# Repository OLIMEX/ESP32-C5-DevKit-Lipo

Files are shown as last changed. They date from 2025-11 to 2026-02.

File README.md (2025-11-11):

# ESP32-C5-DevKit-Lipo
Dual band 2.4Ghz and 5Ghz WiFi 6, Bluetooth 5 LE, Zigbee, Thread, Matter development board UEXT, USB programming, USB JTAG and LiPo battery UPS

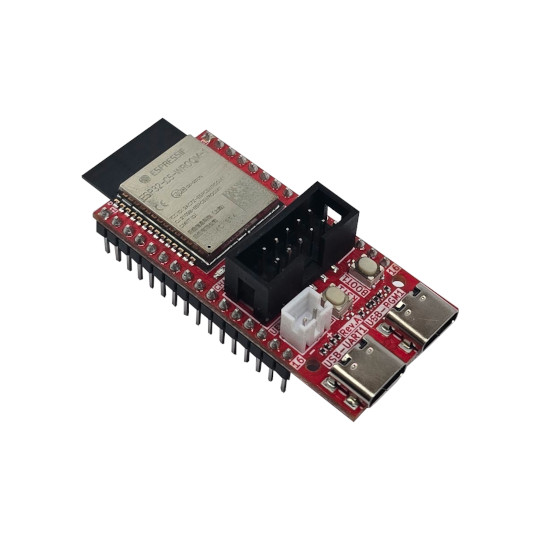
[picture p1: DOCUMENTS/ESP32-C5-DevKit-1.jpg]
ESP32-C5-DevKit-1


https://www.olimex.com/Products/IoT/ESP32-C5/ESP32-C5-DevKit-Lipo/open-source-hardware

Features:

* 32 bit RISC-V processor 240Mhz
* Dual-Band Wi-Fi (2.4 GHz + 5 GHz)
* Bluetooth 5, Zigbee, Thread, Matter
* 8 MB Flash + 4 MB RAM
* UEXT connector
* USB-C (Power & Debug)
* USB-C JTAG
* Boot & Reset buttons
* Extension connector
* 0.9" (22.86 mm) space between the headers
* LiPo UPS charger & step-up converter
* Status LEDs
* Two mouting holes
* Dimensions 53x25mm

## Licenses

* Hardware is released under CERN Open Hardware Licence Version 2 - Strongly Reciprocal, all silkscreen credits to Olimex should remain;
* Software is released under MIT Licensee
* Documentation is released under CC BY-SA 4.0

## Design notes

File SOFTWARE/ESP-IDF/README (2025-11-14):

# ESP32-C5-DevKit-Lipo_low_power_demo - esp-idf project
# After power-on the user led starts blinking. When you hold down USER BUTTON, the LED stops blinking, and the board enters deep_sleep.
# To wake-up the board, you have to press RST button of the board.

#
# How to build the project:
#

# 1. Download esp-idf master branch or tag v5.5.1 (this project has been built with v5.5.1 tag)

git clone https://github.com/espressif/esp-idf.git

# OR

git clone https://github.com/espressif/esp-idf.git -b "v5.5.1"

# 2. Install esp-idf (do this one time only)
# 2.1 Go to esp-idf dir:

cd esp-idf

# 2.2 Run installation script. This will download and install all dependencies

./install.sh

# 3. Export esp-idf to PATH (you must do this every time, when you open terminal)
# 3.1 go to the esp-idf path:

cd PATH_TO_ESP-IDF/esp-idf

# 3.2 Execute the following command as it is, including the . symbol
. ./export.sh

# 3.3 go to the project directory
cd PATH/ESP32-C5-DevKit-Lipo_low_power_demo

# 4. Set target to esp32-c5 (one time only)

idf.py set-target esp32c5

# OPTIONAL: Change  sdkconfig  settings

idf.py menuconfig

# Build:

idf.py build

# Flash (change PORT with the actual port, related to ESP32-C5-EVB)
idf.py flash -p PORT

If everything is done after uploading the project, the led will flash 3 times, then blink evry second.

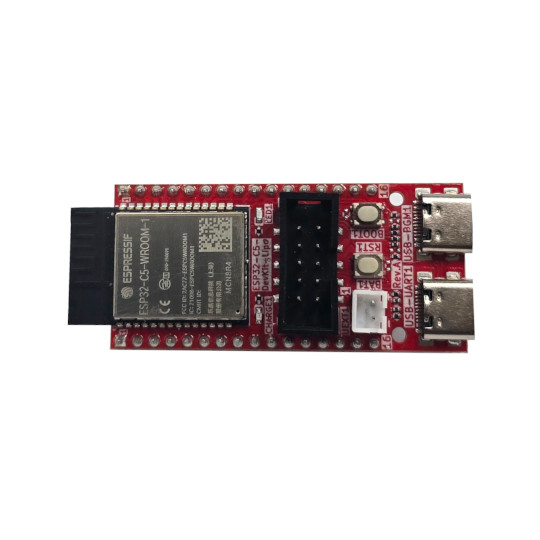
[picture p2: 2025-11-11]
DOCUMENTS/ESP32-C5-DevKit-2.jpg

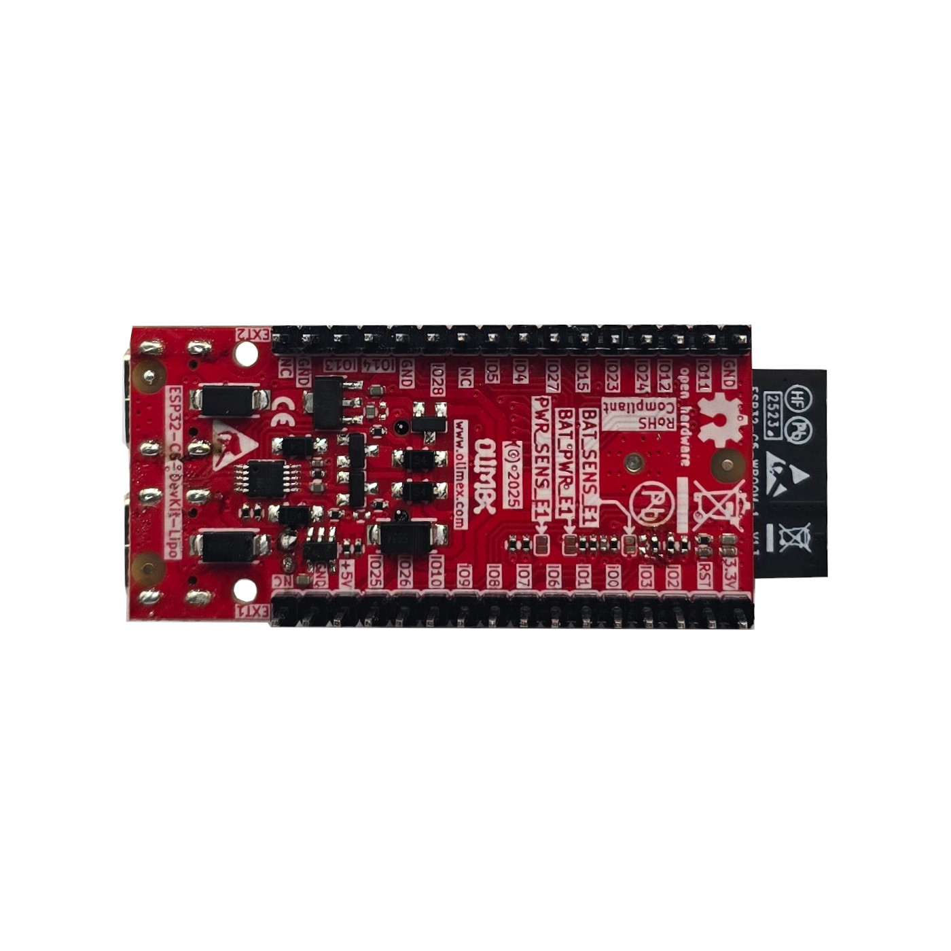
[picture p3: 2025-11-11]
DOCUMENTS/ESP32-C5-DevKit-3.jpg

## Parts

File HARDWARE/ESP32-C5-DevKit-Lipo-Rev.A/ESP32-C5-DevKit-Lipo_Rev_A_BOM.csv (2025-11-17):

Id | Designator | Footprint | Quantity | Designation | Supplier and ref
1 | BOOT1,RST1 | YTS-A016-X | 2 | YTS-A016-X
2 | LED1 | LED_0603_KA | 1 | LED/Green/0603
3 | MH1,MH2 | Mounting_Hole_Drill-2.1mm_Clerance-4mm | 2 | Drill-2.1mm_Clerance-4mm
4 | CHARGE1 | LED_0603_KA | 1 | LED/Yellow/0603
5 | BAT1 | LIPO_BAT_VERTICAL_DW02S | 1 | DW02S
6 | R6,R7 | R_0402_5MIL_DWS | 2 | 33R/R0402
7 | C13,C14 | C_0402_5MIL_DWS | 2 | NA(100nF/10V/20%/X5R/C0402)
8 | FID3,FID4 | Fiducial1x3_Paste | 2 | Fiducial
9 | R2,R5,R1,R3 | R_0402_5MIL_DWS | 4 | 5.1k/1%/R0402
10 | U3 | ESP32-C5-WROOM-1-N4-UNIVERSAL_MODULE | 1 | ESP32-C5-WROOM-1-N8R4
11 | UEXT1 | GBH-254-SMT-10 | 1 | P-B-V-10-LF
12 | R27,R8,R11,R22 | R_0402_5MIL_DWS | 4 | 2.2k/R0402
13 | TVS4,TVS2,TVS1,TVS3 | D_0402_5MIL_DWS | 4 | GG0402052R542P
14 | USB-UART1,USB-PGM1 | USB2.0_TYPE-C(A40-00119-A52-12)_Paste | 2 | USB-C-16P-F(A40-00119-A52-12)
15 | C6,C5 | C_0402_5MIL_DWS | 2 | NA(150pF/50V/2%/NP0/C0402)
16 | FID1,FID2,FID5,FID6 | Fiducial1x3 | 4 | Fiducial
17 | R18,R17,R24 | R_0402_5MIL_DWS | 3 | 470k/R0402
18 | R10,R9,R4,R13,R12 | R_0402_5MIL_DWS | 5 | 10k/R0402
19 | D3,D2,D1 | SMA-KA | 3 | 1N5822/SS34/SMA
20 | C11,C8,C3 | C_0402_5MIL_DWS | 3 | 100nF/10V/20%/X5R/C0402
21 | D7,D5,D6,D4 | SOD-123_1C-2A_KA | 4 | 1N5819S4(SOD-123)
22 | U2 | MSOP-10_Pitch-0.5mm_3.00x3.00x1.00mm | 1 | CH340X(MSOP-10)
23 | R19,R20 | R_0402_5MIL_DWS | 2 | 1k/R0402
24 | R16 | R_0402_5MIL_DWS | 1 | 4.7k/R0402
25 | PWR_SENS_E1,BAT_SENS_E1,BAT_PWR_E1 | SJ_1_SMALLER | 3 | Opened
26 | T2,T1 | SOT23 | 2 | BC817-40(SOT23)
27 | R21,R14 | R_0402_5MIL_DWS | 2 | 0R/R0402
28 | U1 | SOT-23-5 | 1 | TP4054-42-SOT25-R
29 | C7,C12,C10,C2,C1 | C_0402_5MIL_DWS | 5 | 10uF/6.3V/20%/X5R/C0402
30 | C9 | C_0402_5MIL_DWS | 1 | NA(10uF/6.3V/20%/X5R/C0402)
31 | R25 | R_0402_5MIL_DWS | 1 | 220R/R0402
32 | C4 | C_0402_5MIL_DWS | 1 | 1uF/6.3V/10%/X5R/C0402
33 | EXT1,EXT2 | HN1x16 | 2 | HN1x16
34 | VR1 | SOT89-3 | 1 | WL9005P3-33(SOT89-3)
35 | R23 | R_0402_5MIL_DWS | 1 | 220k/R0402
36 | R15 | R_0402_5MIL_DWS | 1 | NA(0R/R0402)
37 | R26 | R_0402_5MIL_DWS | 1 | NA(10k/R0402)
38 | FET1 | SOT23 | 1 | IRLML6402TRPbF

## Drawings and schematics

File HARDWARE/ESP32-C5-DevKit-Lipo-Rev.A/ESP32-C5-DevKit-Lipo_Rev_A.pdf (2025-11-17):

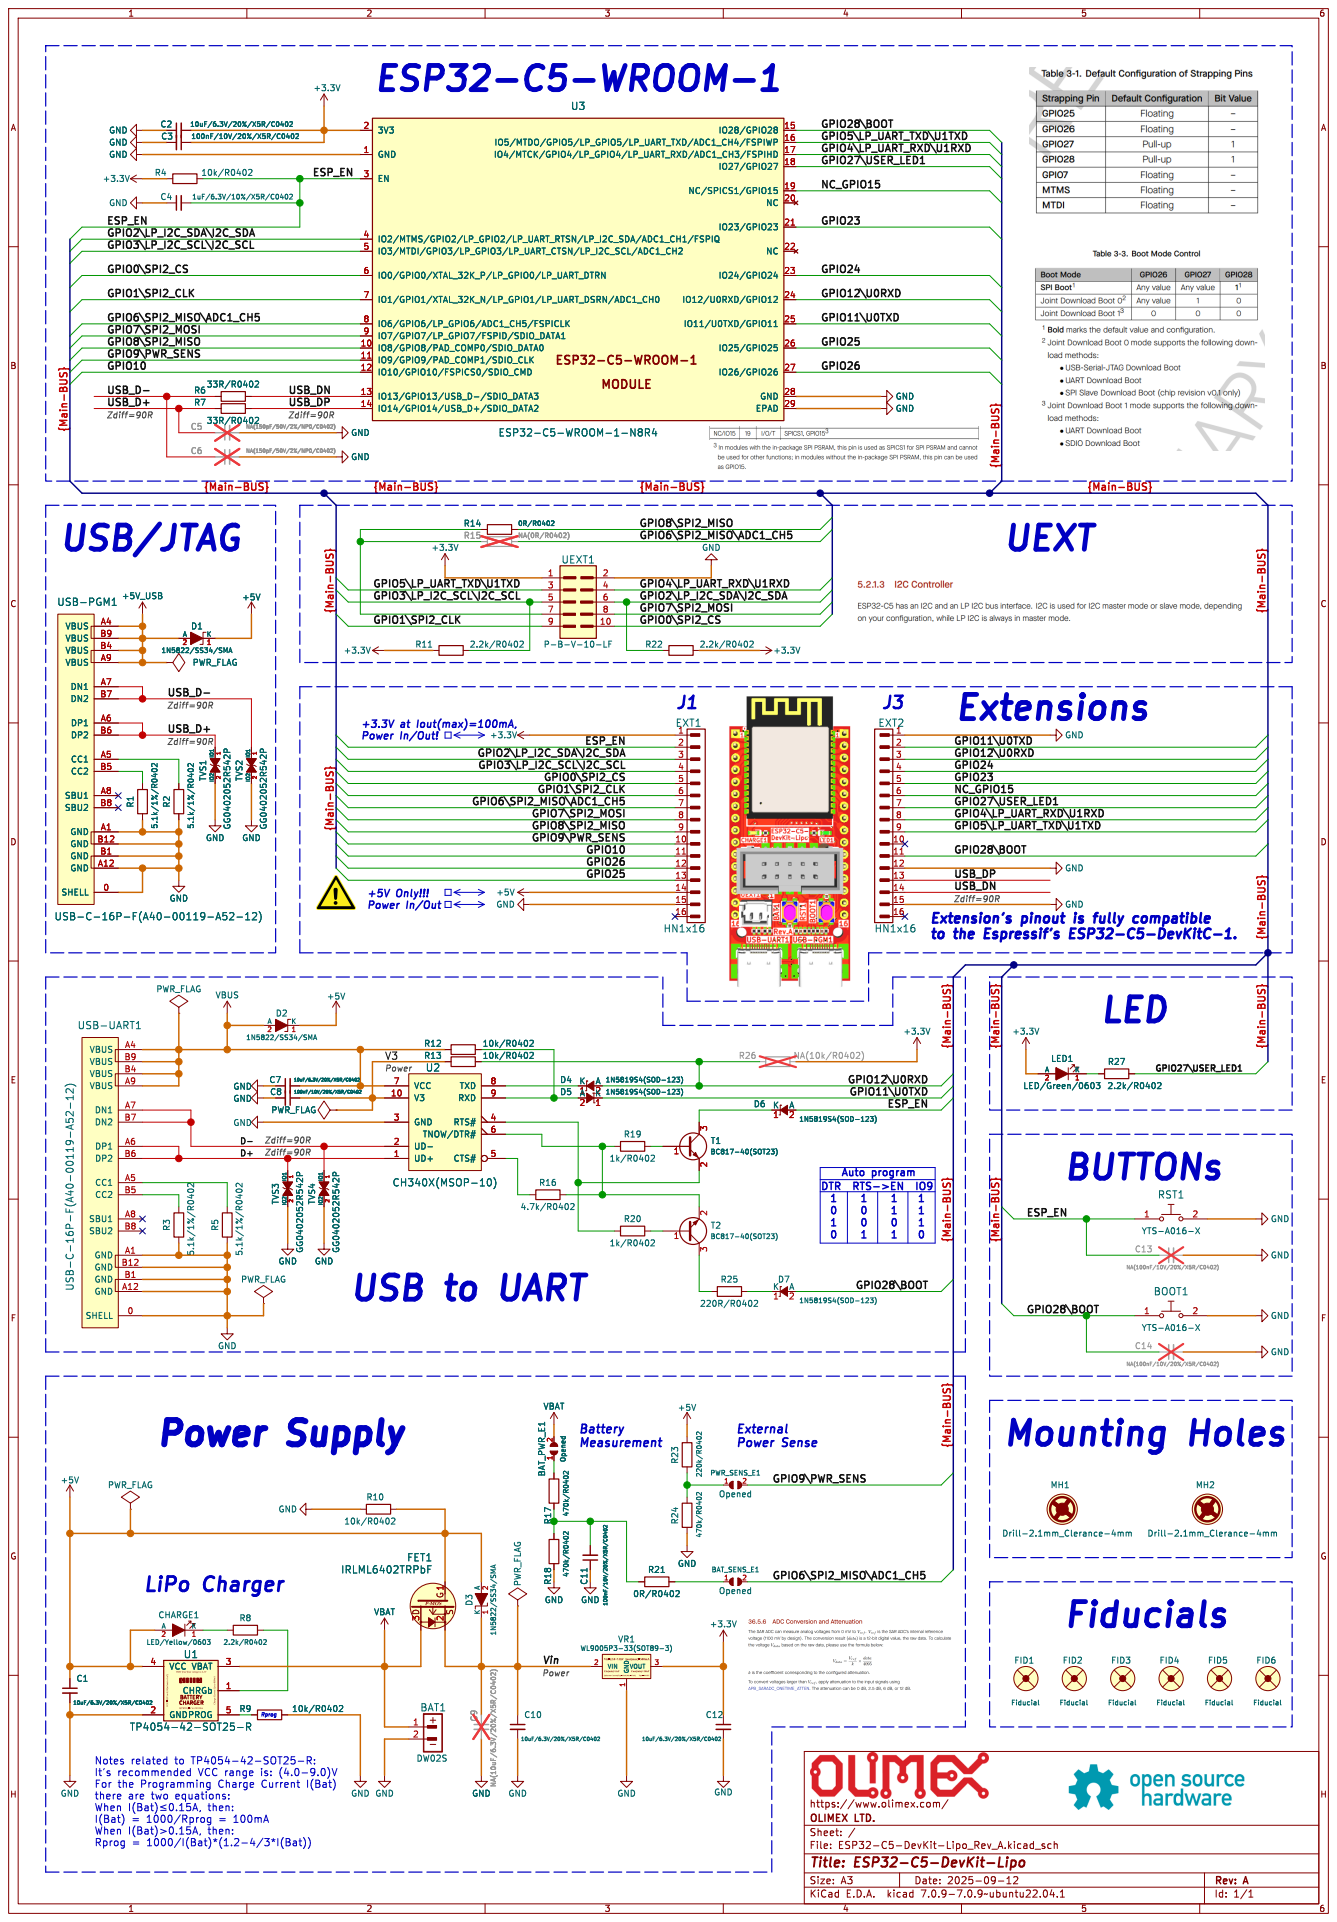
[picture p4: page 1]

2 D3 1N5822/SS34/SMA GND GND C9 NA(10uF/6.3V/20%/X5R/C0402) +5V

+3.3V at Iout(max)=100mA, Power In/Out! +5V Only!!! Power In/Out

to the Espressif's ESP32-C5-DevKitC-1. 0

QuiescentCurrent(Typ=0.3uA;Max=0.7uA) Topr=-40~85C Vin=(2.0~7.0)V GND

Notes related to TP4054-42-SOT25-R:
there are two equations: When þÿI(Bat)"d0.15A, then:

Id: 1/1 Title: ESP32-C5-DevKit-Lipo

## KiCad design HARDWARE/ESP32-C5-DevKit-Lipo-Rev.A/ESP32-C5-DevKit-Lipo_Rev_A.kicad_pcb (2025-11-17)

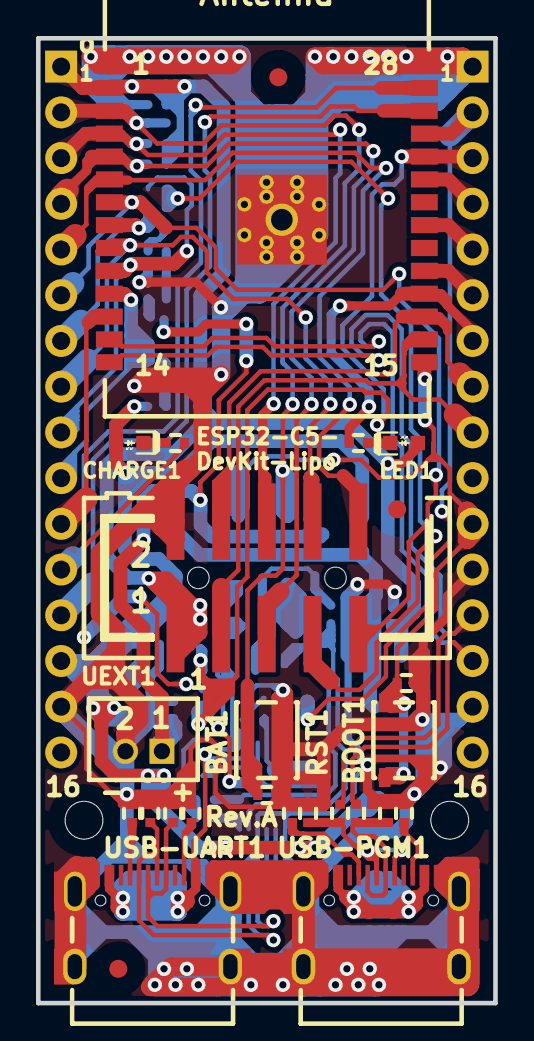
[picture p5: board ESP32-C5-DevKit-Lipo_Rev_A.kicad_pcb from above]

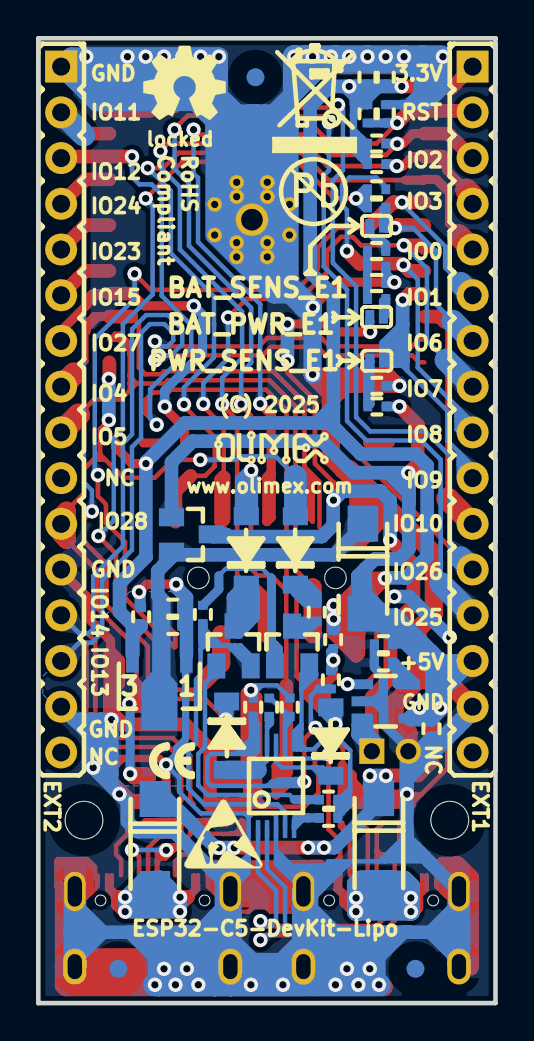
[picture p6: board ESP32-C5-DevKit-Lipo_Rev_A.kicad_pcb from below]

Board: 2 copper layers, 25.4 x 53.6 mm, 86 parts (56 on the bottom side), 58 nets.

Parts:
BAT1: DW02S; LIPO_BAT_VERTICAL_DW02S
BAT_PWR_E1: Opened; SJ_1_SMALLER
BAT_SENS_E1: Opened; SJ_1_SMALLER
BOOT1: YTS-A016-X
C1, C2, C7, C10, C12: 10uF/6.3V/20%/X5R/C0402; C_0402_5MIL_DWS
C3, C8, C11: 100nF/10V/20%/X5R/C0402; C_0402_5MIL_DWS
C4: 1uF/6.3V/10%/X5R/C0402; C_0402_5MIL_DWS
C5, C6: NA(150pF/50V/2%/NP0/C0402); C_0402_5MIL_DWS
C9: NA(10uF/6.3V/20%/X5R/C0402); C_0402_5MIL_DWS
C13, C14: NA(100nF/10V/20%/X5R/C0402); C_0402_5MIL_DWS
CHARGE1: LED/Yellow/0603; LED_0603_KA
D1, D2, D3: 1N5822/SS34/SMA; SMA-KA
D4, D5, D6, D7: 1N5819S4(SOD-123); SOD-123_1C-2A_KA
EXT1, EXT2: HN1x16
FET1: IRLML6402TRPbF; SOT23
FID1, FID2, FID5, FID6: Fiducial; Fiducial1x3
FID3, FID4: Fiducial; Fiducial1x3_Paste
LED1: LED/Green/0603; LED_0603_KA
Logo_OLIMEX_80: Logo_OLIMEX_80
MH1, MH2: Drill-2.1mm_Clerance-4mm; Mounting_Hole_Drill-2.1mm_Clerance-4mm
PWR_SENS_E1: Opened; SJ_1_SMALLER
R1, R2, R3, R5: 5.1k/1%/R0402; R_0402_5MIL_DWS
R4, R9, R10, R12, R13: 10k/R0402; R_0402_5MIL_DWS
R6, R7: 33R/R0402; R_0402_5MIL_DWS
R8, R11, R22, R27: 2.2k/R0402; R_0402_5MIL_DWS
R14, R21: 0R/R0402; R_0402_5MIL_DWS
R15: NA(0R/R0402); R_0402_5MIL_DWS
R16: 4.7k/R0402; R_0402_5MIL_DWS
R17, R18, R24: 470k/R0402; R_0402_5MIL_DWS
R19, R20: 1k/R0402; R_0402_5MIL_DWS
R23: 220k/R0402; R_0402_5MIL_DWS
R25: 220R/R0402; R_0402_5MIL_DWS
R26: NA(10k/R0402); R_0402_5MIL_DWS
RST1: YTS-A016-X
Sign_Antistatic_150: Sign_Antistatic_150
Sign_CE_Small: CE_Sign_Small
Sign_OSHW_7.3x6.0mm: Sign_OSHW_7.3x6.0mm; Sign_OSHW_7.3x6.0mmn
Sign_PB-Free: Sign_PB-Free
Sign_RecycleBin_1: Sign_RecycleBin_1
T1, T2: BC817-40(SOT23); SOT23
TVS1, TVS2, TVS3, TVS4: GG0402052R542P; D_0402_5MIL_DWS
U1: TP4054-42-SOT25-R; SOT-23-5
U2: CH340X(MSOP-10); MSOP-10_Pitch-0.5mm_3.00x3.00x1.00mm
U3: ESP32-C5-WROOM-1-N8R4; ESP32-C5-WROOM-1-N4-UNIVERSAL_MODULE
UEXT1: P-B-V-10-LF; GBH-254-SMT-10
USB-PGM1: USB-C-16P-F(A40-00119-A52-12); USB2.0_TYPE-C(A40-00119-A52-12)_Paste
USB-UART1: USB-C-16P-F(A40-00119-A52-12); USB2.0_TYPE-C(A40-00119-A52-12)_Paste
VR1: WL9005P3-33(SOT89-3); SOT89-3

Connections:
+3.3V: C2.2, C3.1, C12.1, EXT1.1, LED1.2 (A), R4.2, R11.1, R22.2, R26.2, U3.2 (3V3), UEXT1.1, VR1.3 (VOUT)
+5V: C1.1, CHARGE1.2 (A), D1.1 (K), D2.1 (K), D3.2 (A), EXT1.14, FET1.1, R10.1, R23.1, U1.4 (VCC)
+5V_USB: D1.2 (A), USB-PGM1.A4 (VBUS), USB-PGM1.A9 (VBUS), USB-PGM1.B4 (VBUS), USB-PGM1.B9 (VBUS)
/D+: TVS3.1 (IO1), U2.1 (UD+), USB-UART1.A6 (DP1), USB-UART1.B6 (DP2)
/D-: TVS4.1 (IO1), U2.2 (UD-), USB-UART1.A7 (DN1), USB-UART1.B7 (DN2)
/ESP_EN: C4.2, C13.1, D6.2 (A), EXT1.2, R4.1, RST1.1, U3.3 (EN)
/GPIO0\SPI2_CS: EXT1.5, U3.6 (IO0/GPIO0/XTAL_32K_P/LP_GPIO0/LP_UART_D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), UEXT1.10
/GPIO1\SPI2_CLK: EXT1.6, U3.7 (IO1/GPIO1/XTAL_32K_N/LP_GPIO1/LP_UART_D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), UEXT1.9
/GPIO2\LP_I2C_SDA\I2C_SDA: EXT1.3, R22.1, U3.4 (IO2/MTMS/GPIO2/LP_GPIO2/LP_UART_RTSN/LP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), UEXT1.6
/GPIO3\LP_I2C_SCL\I2C_SCL: EXT1.4, R11.2, U3.5 (IO3/MTDI/GPIO3/LP_GPIO3/LP_UART_CTSN/LP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), UEXT1.5
/GPIO4\LP_UART_RXD\U1RXD: EXT2.8, U3.17 (IO4/MTCK/GPIO4/LP_GPIO4/LP_UART_RXD/ADC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), UEXT1.4
/GPIO5\LP_UART_TXD\U1TXD: EXT2.9, U3.16 (IO5/MTDO/GPIO5/LP_GPIO5/LP_UART_TXD/ADC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), UEXT1.3
/GPIO6\SPI2_MISO\ADC1_CH5: BAT_SENS_E1.2, EXT1.7, R15.2, U3.8 (IO6/GPIO6/LP_GPIO6/ADC1_CH5/FSPICLK)
/GPIO7\SPI2_MOSI: EXT1.8, U3.9 (IO7/GPIO7/LP_GPIO7/FSPID/SDIO_DATA1), UEXT1.8
/GPIO8\SPI2_MISO: EXT1.9, R14.2, U3.10 (IO8/GPIO8/PAD_COMP0/SDIO_DATA0)
/GPIO9\PWR_SENS: EXT1.10, PWR_SENS_E1.2, U3.11 (IO9/GPIO9/PAD_COMP1/SDIO_CLK)
/GPIO10: EXT1.11, U3.12 (IO10/GPIO10/FSPICS0/SDIO_CMD)
/GPIO11\U0TXD: D5.1 (K), EXT2.2, U3.25 (IO11/U0TXD/GPIO11)
/GPIO12\U0RXD: D4.2 (A), EXT2.3, R13.2, R26.1, U3.24 (IO12/U0RXD/GPIO12)
/GPIO23: EXT2.5, U3.21 (IO23/GPIO23)
/GPIO24: EXT2.4, U3.23 (IO24/GPIO24)
/GPIO25: EXT1.13, U3.26 (IO25/GPIO25)
/GPIO26: EXT1.12, U3.27 (IO26/GPIO26)
/GPIO27\USER_LED1: EXT2.7, R27.2, U3.18 (IO27/GPIO27)
/GPIO28\BOOT: BOOT1.1, C14.1, D7.2 (A), EXT2.11, U3.15 (IO28/GPIO28)
/NC_GPIO15: EXT2.6, U3.19 (NC/SPICS1/GPIO15)
/USB_D+: C5.1, R7.2, TVS1.1 (IO1), USB-PGM1.A6 (DP1), USB-PGM1.B6 (DP2)
/USB_D-: C6.1, R6.1, TVS2.1 (IO1), USB-PGM1.A7 (DN1), USB-PGM1.B7 (DN2)
/USB_DN: EXT2.14, R6.2, U3.13 (IO13/GPIO13/USB_D-/SDIO_DATA3)
/USB_DP: EXT2.13, R7.1, U3.14 (IO14/GPIO14/USB_D+/SDIO_DATA2)
/V3: C8.1, R13.1, U2.10 (V3)
/Vin: C9.1, C10.1, D3.1 (K), FET1.2, VR1.2 (VIN)
GND: BAT1.2, BOOT1.2, C1.2, C2.1, C3.2, C4.1, C5.2, C6.2, C7.1, C8.2, C9.2, C10.2, C11.1, C12.2, C13.2, C14.2, EXT1.15, EXT2.1, EXT2.12, EXT2.15, R1.1, R2.1, R3.1, R5.1, R9.1, R10.2, R18.2, R24.2, RST1.2, TVS1.2 (IO2), TVS2.2 (IO2), TVS3.2 (IO2), TVS4.2 (IO2), U1.2 (GND), U2.3 (GND), U3.1 (GND), U3.28 (GND), U3.29 (EPAD), UEXT1.2, USB-PGM1.0 (SHELL), USB-PGM1.A1 (GND), USB-PGM1.A12 (GND), USB-PGM1.B1 (GND), USB-PGM1.B12 (GND), USB-UART1.0 (SHELL), USB-UART1.A1 (GND), USB-UART1.A12 (GND), USB-UART1.B1 (GND), USB-UART1.B12 (GND), VR1.1 (GND)
unnamed: BAT_PWR_E1.1, R17.1
unnamed: BAT_SENS_E1.1, R21.2
unnamed: C11.2, R17.2, R18.1, R21.1
unnamed: CHARGE1.1 (K), R8.2
unnamed: D4.1 (K), U2.8 (TXD)
unnamed: D5.2 (A), R12.2, U2.9 (RXD)
unnamed: D6.1 (K), T1.3 (C)
unnamed: D7.1 (K), R25.2
unnamed: LED1.1 (K), R27.1
unnamed: PWR_SENS_E1.1, R23.2, R24.1
unnamed: R14.1, R15.1, UEXT1.7
unnamed: R19.2, T1.1 (B)
unnamed: R20.1, T1.2 (E), U2.4 (RTS#)
unnamed: R20.2, T2.1 (B)
unnamed: R25.1, T2.3 (C)
unnamed: R16.1, R19.1, T2.2 (E), U2.6 (TNOW/DTR#)
unnamed: R8.1, U1.1 (CHRGb)
unnamed: R9.2, U1.5 (PROG)
unnamed: R16.2, U2.5 (CTS#)
unnamed: R2.2, USB-PGM1.A5 (CC1)
unnamed: R1.2, USB-PGM1.B5 (CC2)
unnamed: R5.2, USB-UART1.A5 (CC1)
unnamed: R3.2, USB-UART1.B5 (CC2)
VBAT: BAT1.1, BAT_PWR_E1.2, FET1.3, U1.3 (VBAT)
VBUS: C7.2, D2.2 (A), R12.1, U2.7 (VCC), USB-UART1.A4 (VBUS), USB-UART1.A9 (VBUS), USB-UART1.B4 (VBUS), USB-UART1.B9 (VBUS)

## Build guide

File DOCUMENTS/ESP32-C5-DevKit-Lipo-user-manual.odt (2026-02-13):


ESP32-C5-DevKit-Lipo User Manual

Document revision 2.0 www.OLIMEX.com

# What is ESP32-C5-DevKit-Lipo

ESP32-C5-DevKit-Lipo (https://www.olimex.com/Products/IoT/ESP32-C5/ESP32-C5-DevKit-Lipo/open-source-hardware) is a breadboard-friendly development board with ESP32-C5-WROOM-N8R4 module (8MB of SPI flash memory and 4MB of PSRAM memory) which features dual-band 2.4Ghz and 5Ghz WiFi 6 support, Bluetooth 5 LE support, Zigbee support, Thread and Matter support. The board comes with UEXT connector, DIL GPIO rows, and LiPo battery UPS, dual USB type C connectors, user LED, buttons, and more.

The features of ESP32-C5-DevKit-Lipo (https://www.olimex.com/Products/IoT/ESP32-C5/ESP32-C5-DevKit-Lipo/open-source-hardware) are:

- ESP32-C5-WROOM-N8R4 module: - 32 bit RISC-V processor 240Mhz - Dual-Band Wi-Fi (2.4 GHz + 5 GHz) - Bluetooth 5, Zigbee, Thread and Matter support - 8 MB Flash + 4 MB PSRAM
- USB-C for CH340x USB-serial adapter (power and serial programming)
- USB-C for native USB (power and JTAG debug)
- UEXT connector
- User/boot button
- Reset button
- User LED
- Two extension headers with all GPIOs
- Breadboard-friendly header spacing - 0.9" (22.86 mm)
- Li-Po UPS battery with charger
- Battery charger status LED
- External power sense and battery measurement option
- Two mounting holes
- Compact design size with dimensions 53x25 mm

ESP32-C5-DevKit-Lipo (https://www.olimex.com/Products/IoT/ESP32-C5/ESP32-C5-DevKit-Lipo/open-source-hardware) is an Open Source Hardware project (OSHW), all CAD files and software are available for download, so people can study and modify the design even without a purchase.

+ Important notice: ESP32-C5-DevKit-Lipo (https://www.olimex.com/Products/IoT/ESP32-C5/ESP32-C5-DevKit-Lipo/open-source-hardware) comes without a protective box so be careful where you place it – avoid placing it on metal or conductive surfaces! Do not drop metal or conductive objects on top of the PCB! This can lead to hardware damage.

## Order codes for ESP32-C5-DevKit-Lipo and accessories

ESP32-C5-DevKit-Lipo (https://www.olimex.com/Products/IoT/ESP32-C5/ESP32-C5-DevKit-Lipo/open-source-hardware) ESP32-C5 development board, subject of this document

USB-CABLE-AM-USB3-C (https://www.olimex.com/Products/Components/Cables/USB-CABLE-AM-USB3-C/) High-speed, high-current cable for powering and programming

UEXT modules (https://www.olimex.com/Products/Modules/) Extension modules that can be connected to the on-board UEXT header

BATTERY-LiPo1400mAh (https://www.olimex.com/Products/Power-Supply/Lipo-battery/BATTERY-LIPO1400mAh/) LiPo battery compatible with ESP32-C5-EVB (https://www.olimex.com/Products/IoT/ESP32-C5/ESP32-C5-EVB/open-source-hardware)

BATTERY-CABLE (https://www.olimex.com/Products/Components/Cables/BATTERY-CABLE/) JST2.0 cable can be used for external power supply +5V on PWR1 connector instead to power via USB-C

ESP32-C5-EVB (https://www.olimex.com/Products/IoT/ESP32-C5/ESP32-C5-EVB/open-source-hardware) ESP32-C5 development board with relays and optoisolated inputs

# HARDWARE

## ESP32-C5-DevKit-Lipo layout


ESP32-C5-WROOM

4MB PSRAM

8MB SPI flash

UEXT

BOOT button

RESET button

Lipo battery connector

Watch the polarity!!!

USB-C
Native USB

JTAG

USB-C

UART CH340T

## Power supply

INPUT2

INPUT1

INPUT1 status LED

RESET button

RELAY2

ESP32-C5-DevKit-Lipo (https://www.olimex.com/Products/IoT/ESP32-C5/ESP32-C5-DevKit-Lipo/open-source-hardware) can be powered from several sources:

- USB-UART1 – This is USB-C connector with USB-to-serial converter attached and power function. This port is typically used to connect to a personal computer via USB cable with type C to type A connectors. It allows powering the board and works as debug UART and can be used for programming (with esptool.py or Arduino IDE or ESP-IDF) with automatic bootloader mode invoke (e.g. no need to press any buttons).

- USB-PGM1 – Another USB-C connector connected directly to ESP32-C5 USB pins, it can act as software JTAG and also as software serial. It can also power the board. It should be connected to a personal computer via USB cable (usually with type C to type A connectors).

- Li-Po battery – ESP32-C5-DevKit-Lipo (https://www.olimex.com/Products/IoT/ESP32-C5/ESP32-C5-DevKit-Lipo/open-source-hardware) has smart switching between the different power supplies and LiPo charger, so when USB-C and PWR1 external power supply is missing the LiPo battery with 5V DC step-up converter used to keep all ESP32-C5-DevKit-Lipo (https://www.olimex.com/Products/IoT/ESP32-C5/ESP32-C5-DevKit-Lipo/open-source-hardware) functionality even when powered by a 3.3V battery.

- Connector J1, pin #14 (5V) and pin #15 (GND) – J1 and J2 are 0.1” step connectors exposing all available GPIOs. The 5V power is present there on pin 14 is +5V on pin 15 is GND.

+ Important notice: Never supply more than 5V on pin #14 of J1 header! This will damage the board!

+ Important notice: The USB-C VCC is directly connected to the 5V of pin #14 of J1 header so you shouldn’t apply external power supply to this pin while you are connected to USB-C connector, or there is risk to damage your USB-host.

When working on LiPo battery there are provisions to sense if the board is powered by LiPo battery or external source with GPIO9 and the battery voltage with GPIO6. By default these are not connected so GPIO9 and GPIO6 can be used for other purpose, but SMT jumper can be shorten in case this functionality is necessary.

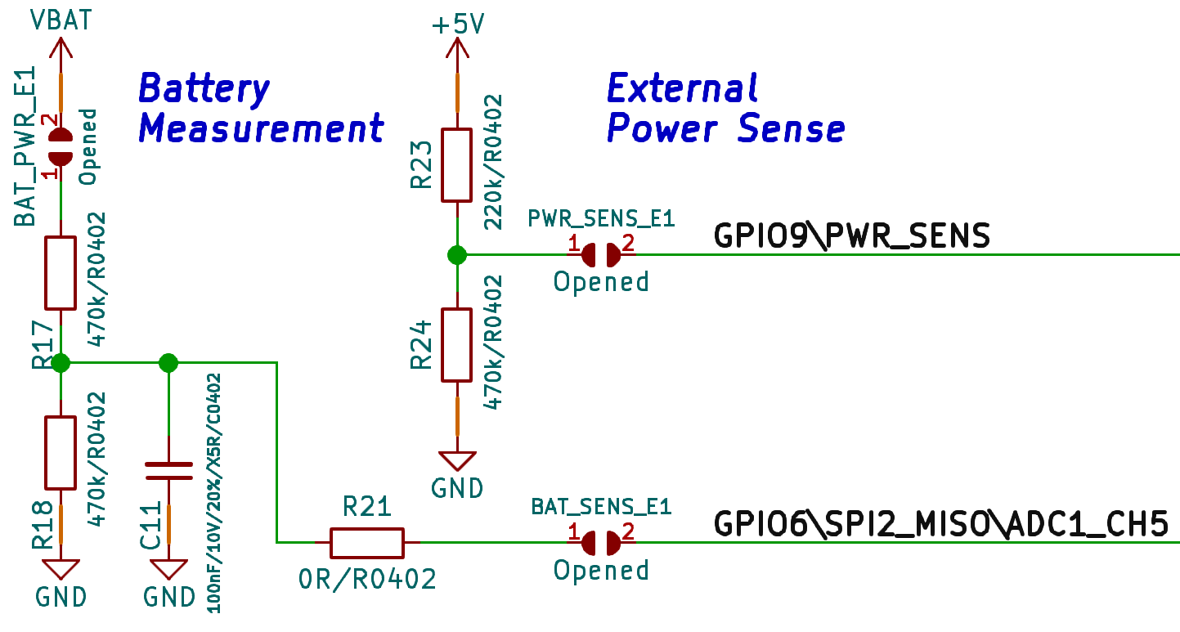
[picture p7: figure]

## UEXT connector

UEXT connector stands for Universal EXTension connector and the purpose is to easily attach Olimex-made expansion boards. Of course, it can be used for any other purpose via jumper wires. The connector contains +3.3V, GND, and pins that can be used for UART, I2C, SPI interfaces. In the case of ESP32-C5 – there are

The UEXT connector is 0.1” 2.54mm step boxed plastic connector. All signals are at 3.3V levels.

Olimex has developed number of MODULES (https://www.olimex.com/Products/Modules/) with this connector. There are temperature, humidity, pressure, magnetic field, light sensors. Modules with LCDs, LED matrix, relays, Bluetooth, Zigbee, WIFI, GSM, GPS, RFID, RTC, EKG, sensors, etc.

## ESP32-C5-DevKit-Lipo UEXT connector

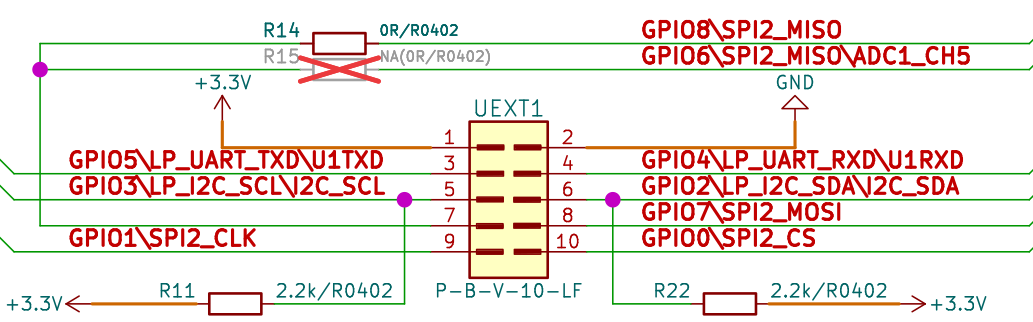
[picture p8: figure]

## J1 and J2 connectors signals

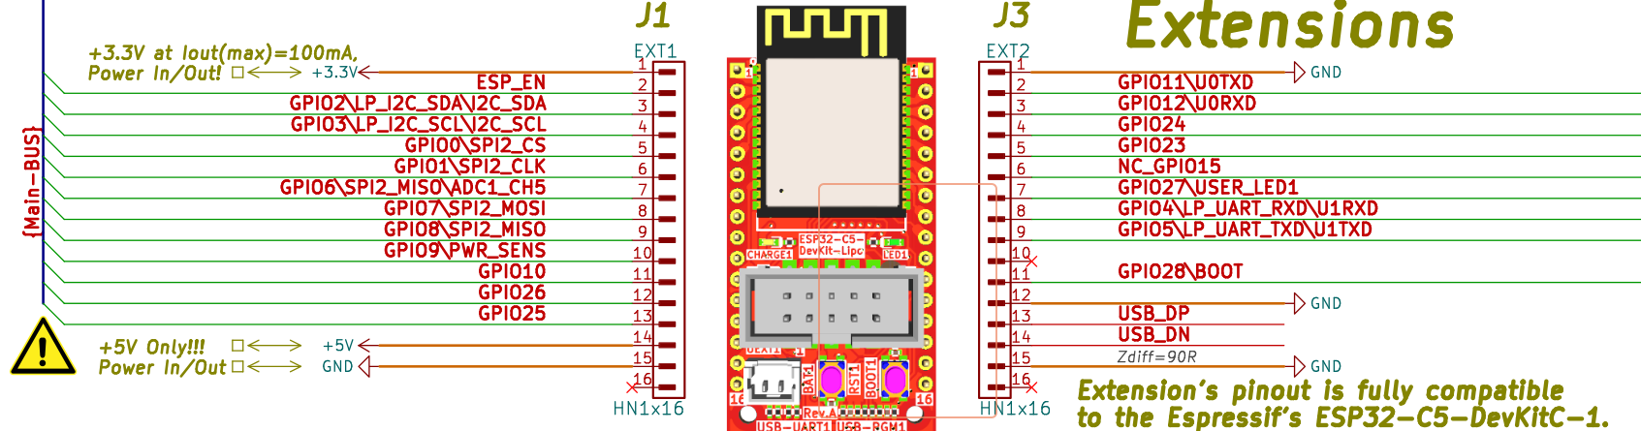
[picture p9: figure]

## LEDs

GPIO27 is connected to GREEN user LED, when the level is LOW LED is ON, when the level is HIGH the LED is OFF.

YELLOW LED for CHARGING status: OFF – battery is fully charged, ON – battery is charging, Blink – No battery.

## ESP32-C5-DevKit-Lipo schematics

ESP32-C5-DevKit-Lipo (https://www.olimex.com/Products/IoT/ESP32-C5/ESP32-C5-DevKit-Lipo/open-source-hardware) latest schematic is available at GitHub:

https://github.com/OLIMEX/ESP32-C5-DevKit-Lipo/tree/main/HARDWARE

# SOFTWARE

ESP32-C5-DevKit-Lipo (https://www.olimex.com/Products/IoT/ESP32-C5/ESP32-C5-DevKit-Lipo/open-source-hardware) can be programmed with any software that supports ESP32-C5 chip. We provide demo examples for Espressif IDF and Arduino, these can be found here:

https://github.com/OLIMEX/ESP32-C5-DevKit-Lipo/tree/main/SOFTWARE

# Document revision history

Revision 2.0 November 2025

- updated schematics to reflect release variant of the board

- improved product description

Revision 1.0 November 2025

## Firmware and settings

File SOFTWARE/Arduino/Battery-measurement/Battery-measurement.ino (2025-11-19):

// Demo for power sense and battery sense
// Compatible with Olimex ESP32-C5-DevKit-Lipo
// Notice! Measuring the battery requires closing PTH jumpers - BAT_PWR_E1 and BAT_SENS_E1;
// External power sense requires closing PTH jumper PWR_SENS_E1;
// Can be configured for other boards changing the #define
// Automatically selects ADC attenuation based on resistor divider

#include "esp32-hal-adc.h" // ensures adc_attenuation_t is visible

// These are GPIO pins for ESP32-C5-DevKit-Lipo, edit for other boards
#define POWER_SENSE 9
#define BATTERY     6

// Adjustable resistor divider coefficient (rC = R1+R7 / R7), edit for other boards
float resistorCoefficient = 2.0;  

// Define maximum input voltage (e.g. battery charger max voltage)
const float batteryMaxVoltage = 4.2;  // volts
// ---------------------------------------------

// Function to auto-select attenuation based on expected voltage range
adc_attenuation_t selectAttenuation(float expectedInputV)
{
  if (expectedInputV <= 1.1)
    return ADC_0db;     // 0–1.1 V
  else if (expectedInputV <= 1.5)
    return ADC_2_5db;   // 0–1.5 V
  else if (expectedInputV <= 2.2)
    return ADC_6db;     // 0–2.2 V
  else
    return ADC_11db;    // 0–3.9 V
}

void setup()
{
  Serial.begin(115200);
  delay(500);

  pinMode(POWER_SENSE, INPUT);
  pinMode(BATTERY, INPUT);

  // Compute expected ADC input voltage based on divider
  float expectedADCVoltage = batteryMaxVoltage / resistorCoefficient;

  // Automatically choose proper attenuation
  adc_attenuation_t batteryAtten = selectAttenuation(expectedADCVoltage);
  adc_attenuation_t powerSenseAtten = ADC_0db; // stays digital but defined for completeness

  // Apply ADC settings
  analogSetPinAttenuation(BATTERY, batteryAtten);
  analogSetPinAttenuation(POWER_SENSE, powerSenseAtten);

  Serial.println("ESP32 Power & Battery Sense Demo");
  Serial.print("Expected ADC voltage: ");
  Serial.print(expectedADCVoltage, 2);
  Serial.print(" V → Using attenuation: ");
  Serial.println((batteryAtten == ADC_0db) ? "0" :
                 (batteryAtten == ADC_2_5db) ? "2_5" :
                 (batteryAtten == ADC_6db) ? "6" : "11");
}

void loop()
{
  // External power sense (digital)
  Serial.print("External power sense: ");
  Serial.println(digitalRead(POWER_SENSE));

  // Battery measurement (analog)
  int battery_mV = analogReadMilliVolts(BATTERY);
  float adjusted_mV = battery_mV * resistorCoefficient;

  Serial.print("Battery measurement: ");
  Serial.print(adjusted_mV, 1);
  Serial.println(" mV");

  Serial.println();
  delay(500);
}

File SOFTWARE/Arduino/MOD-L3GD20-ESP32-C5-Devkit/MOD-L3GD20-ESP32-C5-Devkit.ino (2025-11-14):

/*
  Demo for Olimex MOD-L3GD20 (L3GD20 3-axis gyroscope)
  Board: Olimex ESP32-C5-DevKit-Lipo

  I2C pins (UEXT):
    - SDA -> GPIO2
    - SCL -> GPIO3
  
  Requirements:
    - Arduino IDE with ESP32 board support installed
    - Board selected: "ESP32C5 Dev Module" 

  The demo:
    - Initializes L3GD20 over I2C
    - Configures output data rate and scale
    - Reads gyroscope X/Y/Z angular rate continuously
    - Prints data over Serial
*/

#include <Wire.h>

// L3GD20 default I2C address (SDO = HIGH)
#define L3GD20_ADDR 0x6A

// L3GD20 Registers
#define WHO_AM_I       0x0F
#define CTRL_REG1      0x20
#define CTRL_REG4      0x23
#define OUT_X_L        0x28

void writeReg(uint8_t reg, uint8_t value) {
  Wire.beginTransmission(L3GD20_ADDR);
  Wire.write(reg);
  Wire.write(value);
  Wire.endTransmission();
}

uint8_t readReg(uint8_t reg) {
  Wire.beginTransmission(L3GD20_ADDR);
  Wire.write(reg);
  Wire.endTransmission(false);
  Wire.requestFrom(L3GD20_ADDR, (uint8_t)1);
  return Wire.read();
}

void readGyro(int16_t& x, int16_t& y, int16_t& z) {
  // Auto-increment by setting MSB of register address
  Wire.beginTransmission(L3GD20_ADDR);
  Wire.write(OUT_X_L | 0x80);
  Wire.endTransmission(false);

  Wire.requestFrom(L3GD20_ADDR, (uint8_t)6);

  uint8_t xl = Wire.read();
  uint8_t xh = Wire.read();
  uint8_t yl = Wire.read();
  uint8_t yh = Wire.read();
  uint8_t zl = Wire.read();
  uint8_t zh = Wire.read();

  x = (int16_t)(xh << 8 | xl);
  y = (int16_t)(yh << 8 | yl);
  z = (int16_t)(zh << 8 | zl);
}

void setup() {
  Serial.begin(115200);
  delay(500);

  Serial.println("Initializing L3GD20...");

  // Start I2C on Olimex ESP32-C5 pins SDA=2, SCL=3
  Wire.begin(2, 3);

  // WHO_AM_I check (should return 0xD4 or 0xD7)
  uint8_t whoami = readReg(WHO_AM_I);
  Serial.print("WHO_AM_I = 0x");
  Serial.println(whoami, HEX);

  if (whoami != 0xD4 && whoami != 0xD7) {
    Serial.println("ERROR: L3GD20 not detected!");
    while (true) delay(1000);
  }

  // CTRL_REG1:
  // DR=95Hz, BW=25, Power on, XYZ enabled
  writeReg(CTRL_REG1, 0b00001111);

  // CTRL_REG4:
  // Full scale = 250 dps
  writeReg(CTRL_REG4, 0b00000000);

  Serial.println("L3GD20 initialized.\n");
}

void loop() {
  int16_t gx, gy, gz;
  readGyro(gx, gy, gz);

  // Convert raw to degrees/sec using ±250 dps = 8.75 mdps/LSB
  float x_dps = gx * 0.00875;
  float y_dps = gy * 0.00875;
  float z_dps = gz * 0.00875;

  Serial.print("Gyro (dps): ");
  Serial.print("X=");
  Serial.print(x_dps, 2);
  Serial.print("  Y=");
  Serial.print(y_dps, 2);
  Serial.print("  Z=");
  Serial.println(z_dps, 2);

  delay(200);
}

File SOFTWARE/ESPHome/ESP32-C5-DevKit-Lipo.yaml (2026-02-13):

esphome:
  name: esp32-c5-devkit-lipo
  friendly_name: ESP32-C5-DevKit-Lipo

esp32:
  board: esp32-c5-devkitc-1
  variant: esp32c5
  framework:
    type: arduino

psram:
  mode: opi

# ============================================================
# LOGGING / CONTROL (Native USB)
# ============================================================
logger:

api:
ota:
captive_portal:

wifi:
  ssid: "YOUR_SSID"
  password: "YOUR_PASSWORD"
  ap:
    ssid: "ESP32-C5-DevKit-Lipo Fallback"
    password: "12345678"

# ============================================================
# USER LED — GPIO27
# ============================================================
output:
  - platform: gpio
    pin: GPIO27
    id: user_led_output

light:
  - platform: binary
    name: "ESP32-C5-DevKit-Lipo User LED"
    output: user_led_output

# ============================================================
# BOOT BUTTON — GPIO28
# ============================================================
binary_sensor:
  - platform: gpio
    name: "ESP32-C5-DevKit-Lipo Boot Button"
    pin:
      number: GPIO28
      mode:
        input: true
        pullup: true
      inverted: true
    on_press:
      - light.toggle: user_led_output

# ============================================================
# UEXT I2C — GPIO3 SCL / GPIO2 SDA
# ============================================================
i2c:
  sda: GPIO2
  scl: GPIO3
  scan: true

# ============================================================
# UEXT SPI BUS
# ============================================================
spi:
  clk_pin: GPIO1
  mosi_pin: GPIO7
  miso_pin: GPIO8

# Chip select available:
# GPIO0

# ============================================================
# UEXT UART — GPIO5 TX / GPIO4 RX
# ============================================================
uart:
  - id: uext_uart
    tx_pin: GPIO5
    rx_pin: GPIO4
    baud_rate: 115200

# ============================================================
# CH340 USB-UART (GPIO11 TX / GPIO12 RX)
# DO NOT use these pins for peripherals
# ============================================================

# ============================================================
# OPTIONAL — BATTERY VOLTAGE (GPIO6)
# Enable only if jumpers BAT_PWR_E1 and BAT_SENSE_E1 are closed
# ============================================================
# sensor:
#   - platform: adc
#     pin: GPIO6
#     name: "ESP32-C5-DevKit-Lipo Battery Voltage"
#     attenuation: 11db
#     update_interval: 30s
#     unit_of_measurement: "V"
#     accuracy_decimals: 2
#     device_class: voltage
#     state_class: measurement

# ============================================================
# OPTIONAL — EXTERNAL POWER SENSE (GPIO9)
# Enable only if jumper PWR_SENS_E1 is closed
# ============================================================
# binary_sensor:
#   - platform: gpio
#     name: "ESP32-C5-DevKit-Lipo External Power"
#     pin:
#       number: GPIO9
#       mode: input

# ============================================================
# HARDWARE NOTES — ESP32-C5-DevKit-Lipo
# ============================================================
# Native USB is active by default.
# CH340 USB uses:
#   TX = GPIO11
#   RX = GPIO12
#
# Do not attach peripherals to GPIO11/12 if using CH340.
#
# GPIO0 is SPI CS — avoid pulling LOW at boot.
# GPIO28 is boot button.
# ESP_EN is hardware reset (not GPIO).
#
# 8MB Flash / 4MB PSRAM (OPI mode).

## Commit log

2025-11-11 initial upload
    [ESP32-C5-DevKit-Lipo_Rev_A-B_Cu.gbr, ESP32-C5-DevKit-Lipo_Rev_A-B_Mask.gbr, ESP32-C5-DevKit-Lipo_Rev_A-B_Paste.gbr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]
2025-11-13 Update
    New UEXT demo with MOD-IR-TEMP sensor
2025-11-14 Update
    New demo with MOD-L3GD20 3-axis gyroscope
2025-11-17 Update
    Improved battery measurement circuit before board release
    [ESP32-C5-DevKit-Lipo_Rev_A.kicad_pcb, ESP32-C5-DevKit-Lipo_Rev_A.kicad_sch, ESP32-C5-DevKit-Lipo_Rev_A_BOM.csv]
2025-11-19 Update
    New battery sense and battery voltage demo
2026-04-24 Update olimex_esp32-c5-devkit-lipo.json
    Edited a couple of mistakes based on customer feedback

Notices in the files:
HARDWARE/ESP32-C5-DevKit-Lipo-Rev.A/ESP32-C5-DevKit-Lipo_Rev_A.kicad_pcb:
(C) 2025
